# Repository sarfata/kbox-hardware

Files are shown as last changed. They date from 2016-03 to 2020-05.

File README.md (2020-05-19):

# KBox

## KBox Update - May 2020

Thanks for your interest in KBox! As of May 2020, I am not manufacturing or
selling KBox anymore. All the source code and design files remain available for
your inspiration and if you have any question, feel free to reach out by twitter
message, email or via a github issue.

You might also be interested in my new project, inspired by KBox: [a better sailing analytics
platform](https://www.chartedsails.com/?utm_medium=link&utm_source=github&utm_campaign=kbox).
So if you are looking for a way to [improve your
tacks](https://www.chartedsails.com/blog/learn-from-sailing-data-good-and-bad-tacks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),
[perfect your downind
sailing](https://www.chartedsails.com/blog/learn-from-sailing-data-downwind-technique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)
or just [measure sailing angles and
speeds](https://www.chartedsails.com/blog/five-tools-to-analyze-your-sailing-sessions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),
head over to
[ChartedSails.com](https://www.chartedsails.com/?utm_medium=link&utm_source=github&utm_campaign=kbox).

## What is KBox

KBox is an open-source platform to develop "smart boat" applications.

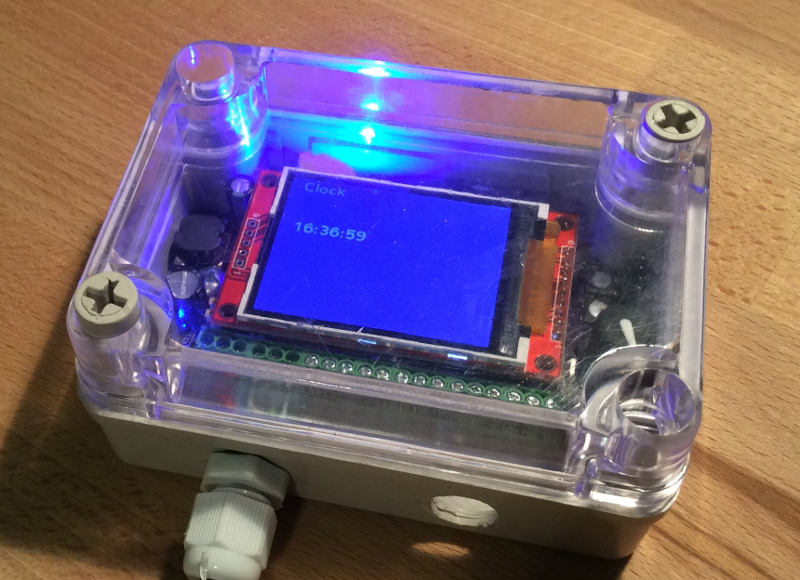
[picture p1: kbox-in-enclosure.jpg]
Picture of KBox


> This repository contains all the hardware files for this project. For firmware,
> please visit the [kbox-firmware](https://github.com/sarfata/kbox-firmware)
> repository.

KBox hardware includes:

 - One NMEA2000 interface,
 - Two NMEA0183 inputs (one of them can be used as a Seatalk input),
 - Two NMEA0183 outputs,
 - One WiFi interface that can connect to an existing network or create a new
   network on your boat,
 - Three analog inputs to measure voltages between 0 and 23V (batteries, solar
   panels, generators, etc),
 - One shunt input to measure current consumption of your main house battery,
 - One barometer,
 - One inertial measurement unit providing a magnetic compass, an accelerometer
   to measure roll, pitch and yaw as well as a gyroscope,
 - An SDCard to record data.

[Find more news about KBox on
hackaday.io](https://hackaday.io/project/11055-kbox).

## How to get KBox?

KBox is an open-source hardware project. You can review the schematics and build
it yourself. We also intend to get a few batches manufactured by a professional
board assembly house. If you are interested, put your name in our form!

[I am interested in an early manufacturing batch](http://goo.gl/forms/y78AeACvyr).

## Schematics

Download the [PDF version of KBox
schematics](https://github.com/sarfata/kbox-hardware/releases/download/kbox-v1-revC/kbox-revC.pdf)
or use Kicad to open this project.

## Pictures

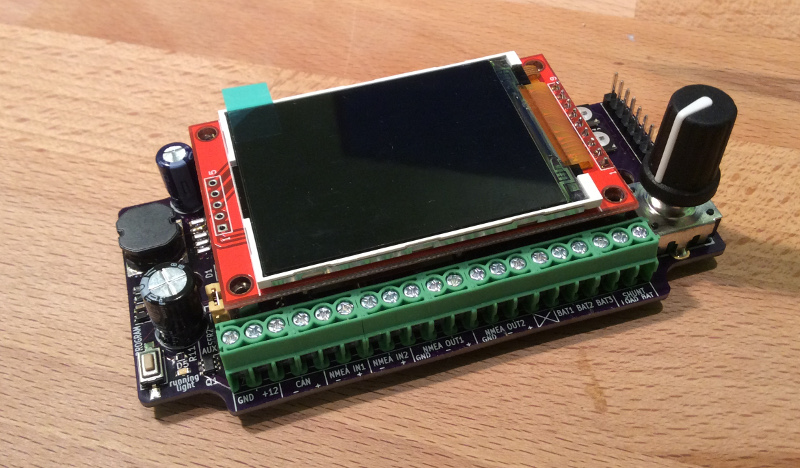
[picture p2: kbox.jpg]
KBox electronics


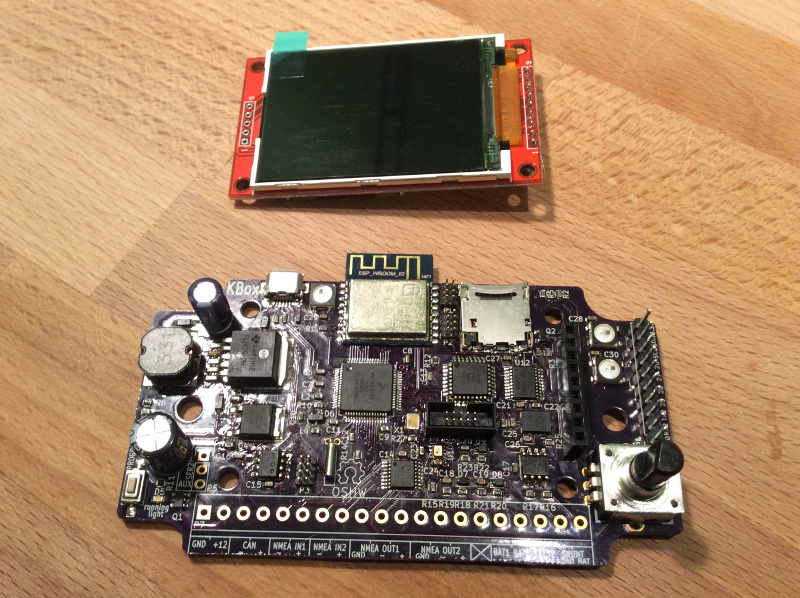
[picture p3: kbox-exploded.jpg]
KBox with the screen removed


**Recommended waterproof enclosure.**

The board was designed to fit in this enclosure and you can easily include
multiple cable glands. The reference of this enclosure is DS-AT-0811-S. It is
available [from Adafruit](https://www.adafruit.com/products/903).

KBox in a waterproof enclosure

## License

The hardware files for KBox are distributed under the [Creative Commons -
Attribution ShareAlike 4.0
license](https://creativecommons.org/licenses/by-sa/4.0/legalcode).

You can share and adapt this project and redistribute it as long as you give
credit to the original authors, clearly indicate if changes were made, and you
re-distribute under a similar license.

## Contributors

- [Thomas Sarlandie](https://github.com/sarfata/)

To contribute to this project, please make a pull-request via GitHub and add
your name to the list of Contributors in that pull-request. Thanks!

## External libraries

A copy is automatically saved by KiCad in the `kbox-cache.lbr` file so you
should not need to have those installed in your computer.

Just in case, here is the list of 3rd party libraries used:

For the schematic:

 - [kicad_libs]: w_analog, w_device, conn
 - [gsg-kicad-lib]: gsg-symbols

For the PCB:

 - [kicad_libs]: w_smd_trans (will disappear soon), w_misc_comp (rotary encoder)
 - [gsg-kicad-lib]: gsg-modules (micro usb connector)

[kicad_libs]: git://smisioto.eu/kicad_libs.git
[gsg-kicad-lib]: git@github.com:greatscottgadgets/gsg-kicad-lib.git

### A note on git subtrees

This project use of git subtrees to reference footprints from various libraries
on the web. It works great and should make everyone's life easier but when you
need to pull changes from the original repo or push back some updates, it can be
slightly non trivial ...

So here is the best reference I have found:
https://hpc.uni.lu/blog/2014/understanding-git-subtree/

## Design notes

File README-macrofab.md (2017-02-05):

# How to manufacture with macrofab

- Generate GERBER and Drill files normally
- Upload all files
- Generate BOM CSV with ./bom2csv.xsl
- Use script to replace values in kicad_pcb file with part numbers

    python ../macrofab-bom-in-pcbnew-values.py ../kbox.kicad_pcb ../kbox.csv
    kbox-macrofab.kicad_pcb --substitute ../bom-substitutions.csv

- Upload kicad_pcb file
- Remove DNP parts as well as VIA and graphics (make them do not populate)
  They should all have the value DNP and be pre-selected.
- Make P1,P2,P3,P6 DNP
- Manually fix inventory parts (need to re-input their value and select
  inventory)

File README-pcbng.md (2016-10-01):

# How to manufacture via pcb.ng

 - Generated gerber files via the standard KiCad export gerber window
 - Upload all the files as one zip - Everything should be automatically
   recognized
 - Generated drill like usual (one file only for pcbng so check the option to
   merge plated and non-plated holes)
 - Generate the 'XYRS' file from pcbnew in CSV format
 - Upload it
 - Generate the BOM from eeschema in XML and then run it from bom2csv.xslt in
   this project

       xsltproc -o "%O.csv" /usr/local/lib/kicad/plugins/bom2csv.xsl "%I"

   This will export only Reference, Value, PartNumber

 - Upload the bom

## notes

- eia481 defines how parts are placed in reels:
  http://www.bbs.dianyuan.com/bbs/u/39/1141628341.pdf
- inverted manually (180) the sdcard. should fix the footprint. I believa eai481
  says the pins should be at the top.
- not sure about where the centroid of the usb connector should be. (FIXED - I
  think)

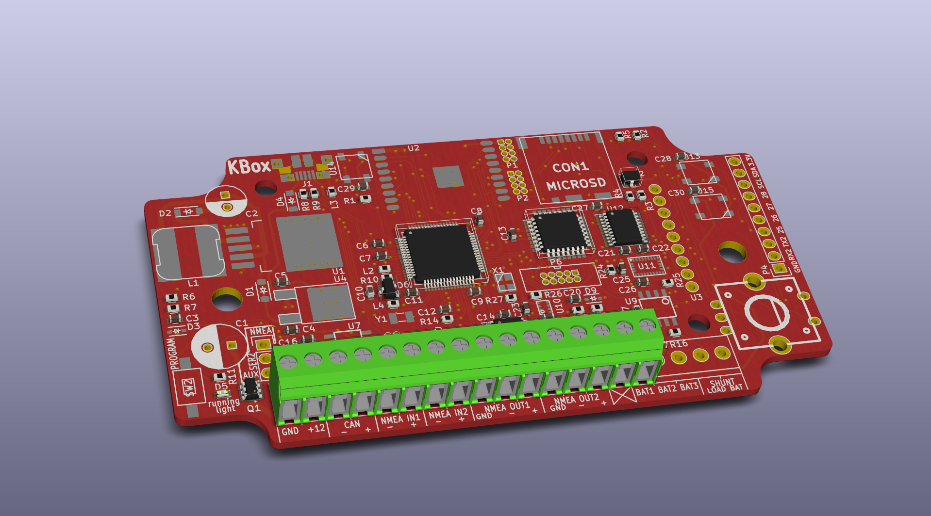
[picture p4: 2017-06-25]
kbox-board-render.png

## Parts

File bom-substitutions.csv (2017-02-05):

PartNumber | Substitute | Description
CC0603KPX7R7BB104 | MF-CAP-0603-0.1uF | 0603 .1uF
RC0603JR-0710KL | MF-RES-0603-10K | 0603 10k
RC0603JR-074K7L | MF-RES-0603-4.7K
RC0603JR-07470RL | MF-RES-0603-470
LTST-C190KFKT | MF-LED-0603-GREEN
ESP8266_ESP_13_WROOM_02 | ESP-WROOM-02

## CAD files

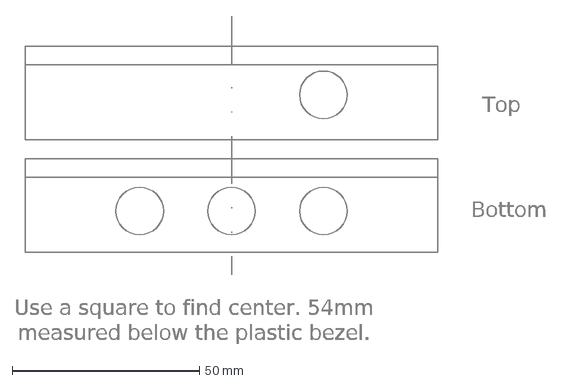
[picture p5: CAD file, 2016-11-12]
at-0811-s-drilling.dxf
Top
Use a square to find center. 54mm measured below the plastic bezel.
Bottom

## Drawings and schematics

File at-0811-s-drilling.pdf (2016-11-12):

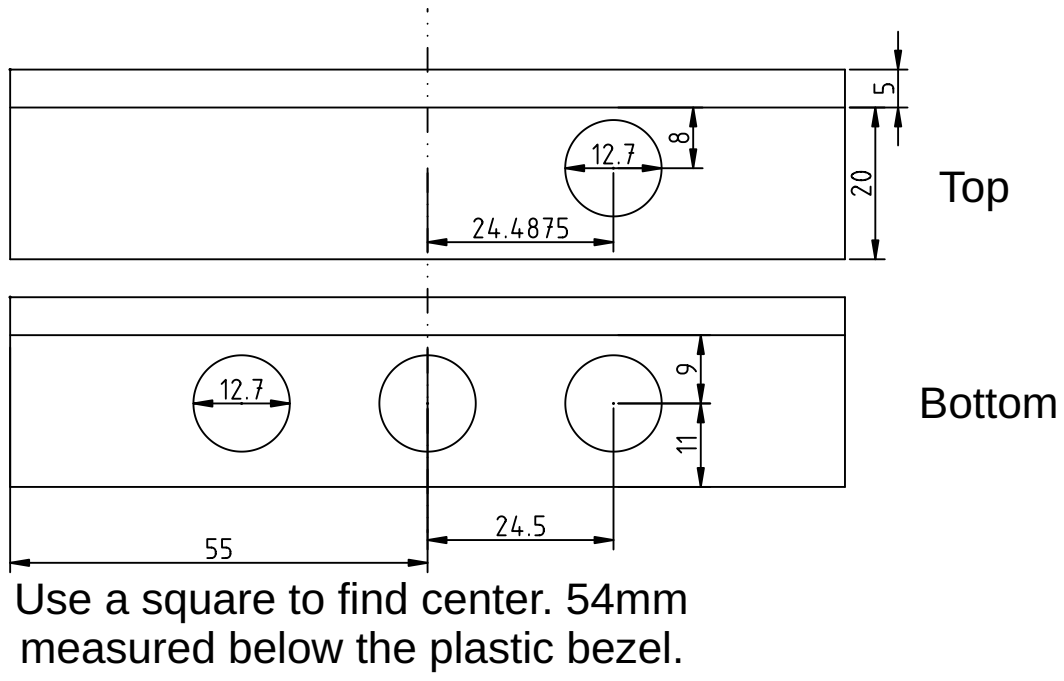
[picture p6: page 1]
Top; Bottom

Use a square to find center. 54mm
measured below the plastic bezel.

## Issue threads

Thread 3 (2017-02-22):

Regulated voltage output for resistance measurement

neftaly, 2017-02-22:
Provide a regulated calibrated vout pin (perhaps on the NC pin to the left of battery inputs), allowing for easy connection of resistive sensors such as tank level monitors, rudder angle monitors, etc.

neftaly, 2017-02-22:
Also consider renaming battery 1/2/3 to analogue 1/2/3

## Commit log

2015-11-26 v1 ...
    [bb1.kicad_pcb, bb1.sch]
2015-11-30 v0.1 almost done now. Schematic + Board
    [adc-inputs-ac.sch, adc-inputs.sch, bb1.kicad_pcb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]
2015-12-01 Fine tuning of the board
    - Added test headers for serial1, serial2 and can (at 3.3v levels)
    - Added solder jumpers to disconnect serial2 from rs232 converter
    [bb1.kicad_pcb, bb1.sch, nmea.sch]
2015-12-05 Continued work on the PCB. Lots of footprint work.
    [bb1.kicad_pcb, bb1.sch, nmea.sch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]
2015-12-07 Finalized v1 revA
    - Added BNO055
    - Fixed SOIC8 pattern
    - Replaced phoenix connectors by a 20 pol
    - Many fine tuning/cosmetic adjustments
    - Sent files to manufacturing. Will tag this commit.
    [bb1.kicad_pcb, bb1.sch, nmea.sch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]
2015-12-07 Renamed bb1 into hardware-v1
    [adc-inputs-ac.sch, adc-inputs.sch, bb1.kicad_pcb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]
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2015-12-07 remove unused teensy31 library
    [bb1.sch, nmea.sch, sensors.sch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]
2015-12-07 Squashed 'hardware-v1/kicad-ESP8266/' changes from e81df77..9440d24
    9440d24 Changed the GND pins to be Power Pins to avoid ERC errors
    git-subtree-split: 9440d24dc7904a3ab39dba2ac186cb68e8994159
    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
2015-12-09 Changed minimal annular ring from 2 mils to 5 mils
    [bb1.kicad_pcb]
2015-12-09 moved one trace that was to close to a pad according to advanced circuits
    [bb1.kicad_pcb]
2015-12-30 More conservative project settings
    Should be compatible with SeeedStudio FusionPCB, OSHPark, DirtyPCBs and
    Advanced Circuits.
    [bb1.kicad_pcb]
2015-12-30 adjusted vias sizes and text sizes. fixed DRC errors
    [bb1.kicad_pcb]
2016-01-19 add a REWORK file with known problems for each version of the board
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2016-01-19 Connect DEBUG line to MK02 reset line (with 0 ohm)
    With a 0 ohm so that when PJRC comes up with bootloader that do not need
    it, we will remove it.
    [teensy.sch]
2016-01-19 Remove backlight pull up to save a few mA when snoozing
    [bb1.sch]
2016-01-19 add decoupling caps on ws2812b
    [bb1.sch]
2016-01-19 Added an optional level shifter on the WS2812 RGB leds.
    [bb1.sch, nmea.sch, sensors.sch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]
2016-01-20 remove mcp2562 pull up (there is an internal one)
    [nmea.sch]
2016-01-20 remove mpl3115a2 barometer (keep bmp280)
    [sensors.sch]
2016-01-20 invert nmea signals
    [nmea.sch]
2016-01-20 Add i2c addresses on schematic
    [nmea.sch, sensors.sch]
2016-01-20 Add 10ohms resistor to protect ina219
    [nmea.sch]
2016-01-20 Make DISP_DC a hardware CS line
    [bb1.sch]
2016-01-20 Pull Wifi GPIO2 up - Add GPIO5 to wifi debug header
    [bb1.sch]
2016-01-20 Connect IMU_RESET to teensy
    [bb1.sch, sensors.sch]
2016-01-20 Move SER2 break out pins to aux header
    Add jumper to switch between nmea and aux (instead of solder jump)
    [bb1.sch, nmea.sch]
2016-01-26 Jumper to select Ser2 role + 3V voltage ref
    [bb1.sch, teensy.sch]
2016-01-27 Replace SN7534051 by SN65C1168E to save power
    [nmea.sch]
2016-01-27 Added fdc654p for reverse voltage protection
    [bb1.sch]
2016-01-29 Removed solder jumper on the reset line by a DNP 0 ohms
    [teensy.sch]
2016-01-29 re-annotate schematic
    [bb1.sch, nmea.sch, sensors.sch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]
2016-01-30 Footprint work
    - Fix ina219 footprint (for soic)
    - lm4040
    - sn65c1168e -> tssop16
    - sn74hct245 -> tsso20
    - updated bunch of caps to normal 0603 (not handsolder)
    [bb1.sch, nmea.sch, sensors.sch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]
2016-01-30 fix tl2575
    [bb1.sch, nmea.sch, teensy.sch]
2016-01-30 removed custom solder mask clearance - will use project settings instead
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2016-01-30 Squashed 'hardware-v1/kicad-ESP8266/' changes from 1e8fdf8..e082610
    e082610 Merge pull request #1 from jdunmire/master
    10e8ec0 Swap GPIO4/5 on ESP-12
    972690e Merge pull request #11 from skorokithakis/master
    caf49ff Show the ESP-12's 3D model for the ESP-12E.
    a761f49 Merge pull request #9 from sarfata/fix-esp13-gnd-pins
    REVERT: 1e8fdf8 Add GND pad to the ESP13/WROOM-02 module
    git-subtree-split: e0826106b15099f6f641eb569354dff6a387fd4b
    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
2016-01-31 Switch MCP2562 to SOIC8N (not handsolder)
    [bb1.sch, nmea.sch]
2016-01-31 Switch INA219 to SOIC8N (non handsolder)
    [nmea.sch]
2016-01-31 add sheet with rgb leds and level shifter
    [rgbs.sch]
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2016-02-01 First draft of revision B
    Lots of changes to the board. Almost completely re-layed out.
    Will do some verification now.
    [bb1.kicad_pcb, bb1.sch, nmea.sch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]
2016-02-01 Finalizing revB
    - Added part numbers on all parts (in kicad PartNumber field)
    - Some finicking in a bunch of corners
    [bb1.kicad_pcb, bb1.sch, nmea.sch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]
2016-02-02 PCB final touches
    - Added via stitches on power components
    - Added ground plane on bottom copper layer to help with power
    dissipation (acts as heatsink)
    - Increased .05" header pads to avoid DFM warnings (annular ring was
    too close to minimum)
    [bb1.kicad_pcb]
2016-02-02 adding oring diodes to schematic
    [bb1.sch, teensy.sch]
2016-02-02 Final touches + v1revb sent to oshpark
    [bb1.kicad_pcb, bb1.sch, nmea.sch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]
2016-03-11 Fixing SDA/SCL inversion on U9
    [bb1.kicad_pcb, bb1.sch]
2016-03-11 Change reference of 10k .1% resistors
    [bb1.sch, nmea.sch]
2016-03-11 Bump to revC
    [bb1.kicad_pcb]
2016-03-15 Rename folders, add readme
    [adc-inputs-ac.sch, adc-inputs.sch, bb1.kicad_pcb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]
2016-03-15 more renaming
    [kbox.kicad_pcb, kbox.sch]
2016-03-15 More renaming from bb to kbox
    [kbox.sch, nmea.sch, rgbs.sch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]
2016-04-14 add revC on schematic
    [kbox.sch]
2016-04-14 fix the attributes on some parts to get correct pick n place output
    [kbox.kicad_pcb]
2016-06-08 Fixing U1 and U4 footprint to have their center in the middle
    This problem was reported by pcb.ng.
    Also some left over changes from renaming bb into kbox which pollutes
    this commit, as well as upgrading to Kicad 4.1 beta to get csv export of
    xyrs files.
    [kbox.kicad_pcb]
2016-06-17 wip of v1d
    [kbox.kicad_pcb, kbox.sch, sensors.sch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]
2016-09-30 Steps to v1d
    - Thru-hole capacitors are back (smds are too big)
    - 32kHz crystal replaced by a SMD variant
    - some cleanup for DRC
    [kbox.kicad_pcb, kbox.sch, nmea.sch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]
2016-09-30 Remove WS2812/ESP/MK02 from paste layer
    [kbox.kicad_pcb]
2016-09-30 Update revision id on bottom silkscreen
    [kbox.kicad_pcb]
2016-09-30 Remove extra properties on 32k crystal to help with export
    [teensy.sch]
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2016-10-01 Pushed v1d to pcb.ng
    - Fixed orientation of USB connector and Crystal
    - Updated pcbng upload instructions
    [kbox.kicad_pcb]
2016-10-01 Reposition usb-connector centroid based on pcb.ng feedback
    [kbox.kicad_pcb]
2016-10-01 Fixing some parts numbers for pcbng import
    [kbox.kicad_pcb, kbox.sch, nmea.sch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]
2016-10-01 Re-add paste layer for "consigned" parts
    - RGB ws2812 U13/U14/U15
    - Teensy bootloader / mk02
    - ESP8266
    Also fixed position of labels for P1 and P2
    [kbox.kicad_pcb]
2016-10-01 Update revision on silkscreen
    [kbox.kicad_pcb]
2016-10-02 Preparing for macrofab
    - Script to update values in kicad file
    - Add MPN to parts that will be consigned
    [rgbs.sch, teensy.sch]
2016-10-02 Finalized macrofab order (v1e)
    [kbox.kicad_pcb]
2016-11-12 Add mechanical drawings for enclosure holes
    [at-0811-s-drilling.dxf]
2017-02-03 Removed SW1
    [kbox.sch]
2017-02-03 Removed SW1, fixed vias under screws, added S/N on back
    [kbox.kicad_pcb]
2017-02-03 Remove R12
    This was the 0 ohms to connect the reset pin of the MKL02 to the DEBUG
    pin of the cortex debug connector so that this chip is offline when we
    are connected via SWD.
    [kbox.kicad_pcb, teensy.sch]
2017-02-03 Fix centroid on ILI9341
    Put the centroid in the center of the actual through-hole part so that
    it can be automatically placed.
    [kbox.kicad_pcb]
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2017-02-04 Fix orientation of WS2812 footprints
    [kbox.kicad_pcb]
2017-02-04 Fix orientation of DM3CS-SF
    [kbox.kicad_pcb]
2017-02-05 Macrofab script improvement
    Now handles DNP and substitutions
    [bom-substitutions.csv]
2017-06-24 Update to kicad 4.0.6
    [kbox.sch, teensy.sch]
2017-06-25 Make files readable with kicad 4.0.6
    [kbox.kicad_pcb]
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2018-02-01 Updated schematic for v1.1
    - 12V will now be measured before the input protection
    - Removed IMU_INT and IMU_EN from extension connector
    - Added +5V and +12V on extension connector
    - Removed 1 on of the two grounds included with NMEA outputs
    - Added a pulse input on the main connector, with input protection
    - Split the 20pin connector into two separate connector. Changed to a
    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
    [kbox.sch, nmea.sch, rgbs.sch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]
2018-02-02 PCB changes for kbox 1.1a
    Plus a few minor part reference changes to match what is available now.
    [kbox.kicad_pcb, kbox.sch, nmea.sch]
